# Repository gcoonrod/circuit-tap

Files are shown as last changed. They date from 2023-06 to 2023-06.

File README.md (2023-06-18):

<!--
 Copyright 2023 Greg Coonrod
 
 Licensed under the Apache License, Version 2.0 (the "License");
 you may not use this file except in compliance with the License.
 You may obtain a copy of the License at
 
     http://www.apache.org/licenses/LICENSE-2.0
 
 Unless required by applicable law or agreed to in writing, software
 distributed under the License is distributed on an "AS IS" BASIS,
 WITHOUT WARRANTIES OR CONDITIONS OF ANY KIND, either express or implied.
 See the License for the specific language governing permissions and
 limitations under the License.
-->

# Circuit Tap

A low-speed digital logic analyzer designed around 74HC165 shift registers and the ATMega4809 MCU.

## Design

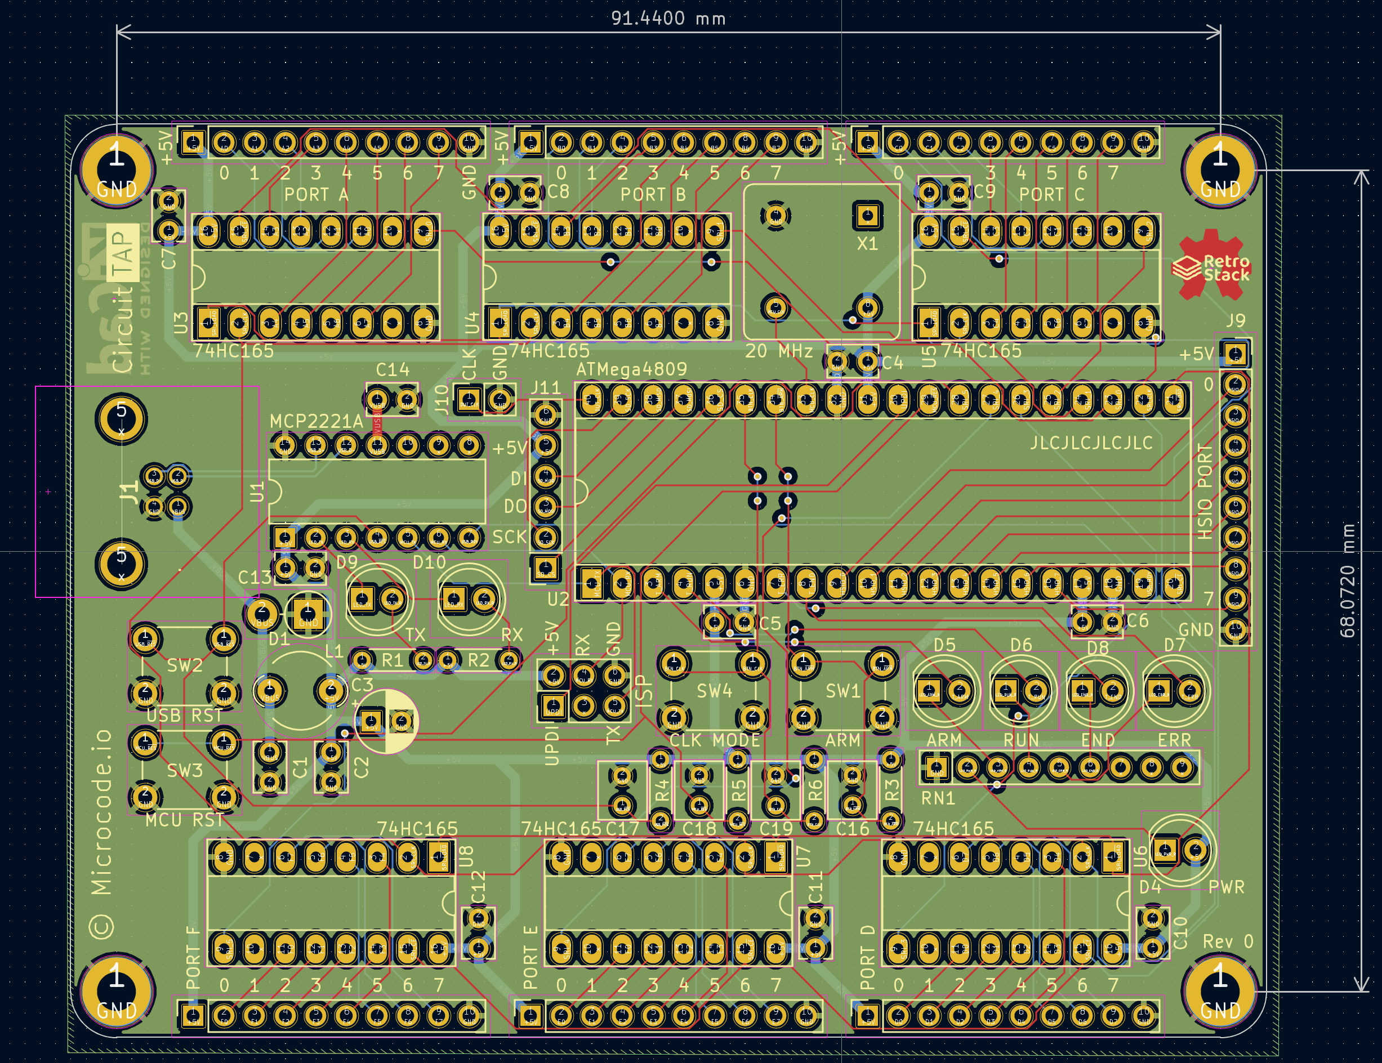
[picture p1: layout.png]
layout


The Circuit Tap is designed to serve as a digital logic analyzer for primarily low speed circuits (<= 1Mhz). It is intended to aid in debugging the [RetroStack](https://github.com/gcoonrod/retro-stack), a 6502 based hobbyist computer. As I do not (at the time of designing this tool) own an oscilliscope or logic analyzer, I needed a way to monitor the address bus, data bus, and numerous control signals of the RetroStack while the clock was freely running. For very simple programs it was sufficient to use a manually stepped clock to debug, but the addition of IO peripherals and more complex programs have made it prohibitively time consuming to continue manual clock control.

### Data Capture

The Circuit Tap has 6 low speed 8-bit input ports and one full speed 8-bit port. The low speed ports are implemented with 74HC165 parallel load shift registers which allows for the simultaneous capture of up to 48 signals on a single clock transition. However, those bits must be shifted out before (~10 mcu clock cycles) before another sample can be taken. This is the primary limiting factor for the sampling speed of the low speed inputs. The full speed port is directly mapped to Port D of the 4809 and can be read from or written to as fast as the mcu is capable.

### Goals

- Reliably capture signals at ~1Mhz
- Read test plans from an SD card or UART
- Write test results to SD or UART
- Integrate with desktop GUI (TBD)
- Drive external clock and control lines
- Trigger off external clock and control lines

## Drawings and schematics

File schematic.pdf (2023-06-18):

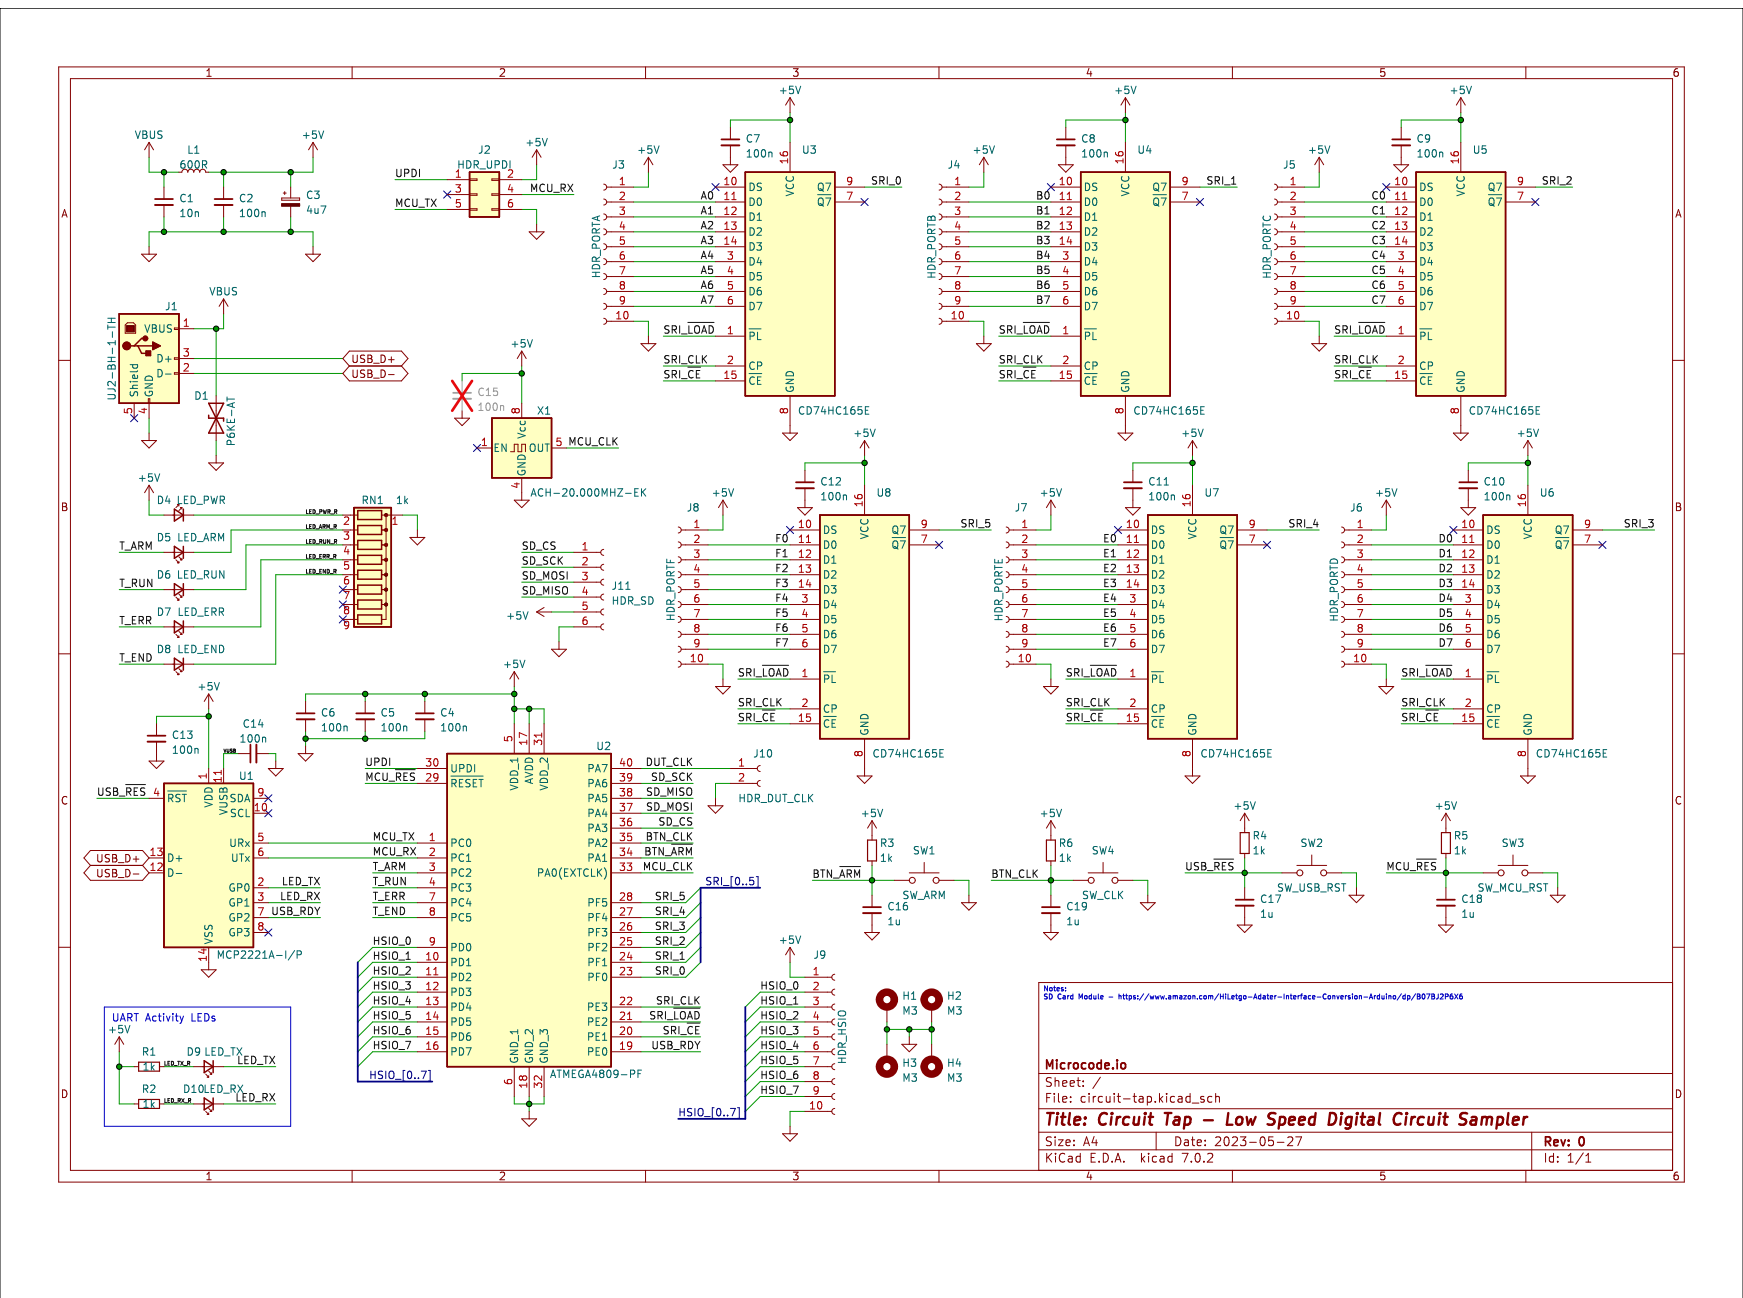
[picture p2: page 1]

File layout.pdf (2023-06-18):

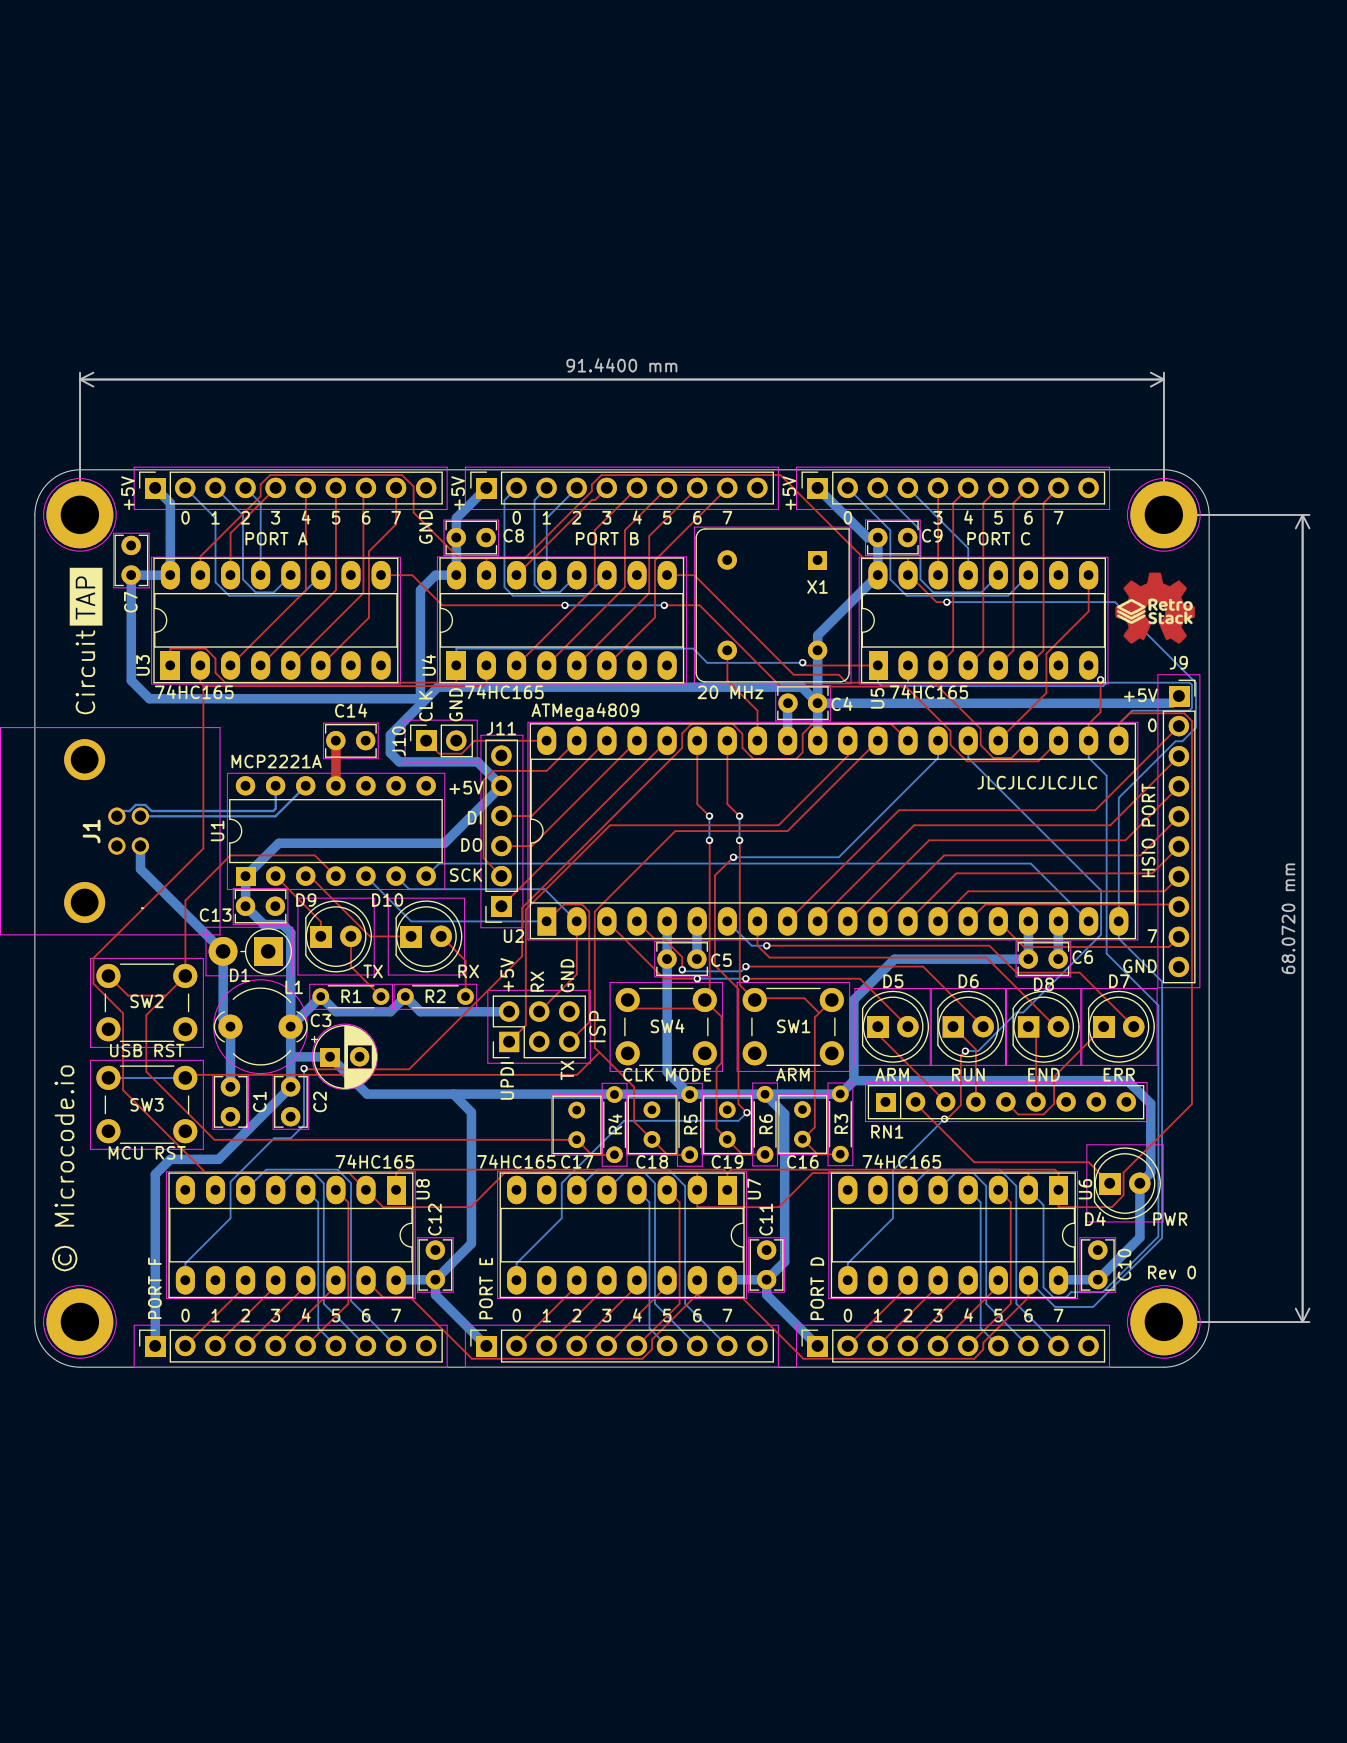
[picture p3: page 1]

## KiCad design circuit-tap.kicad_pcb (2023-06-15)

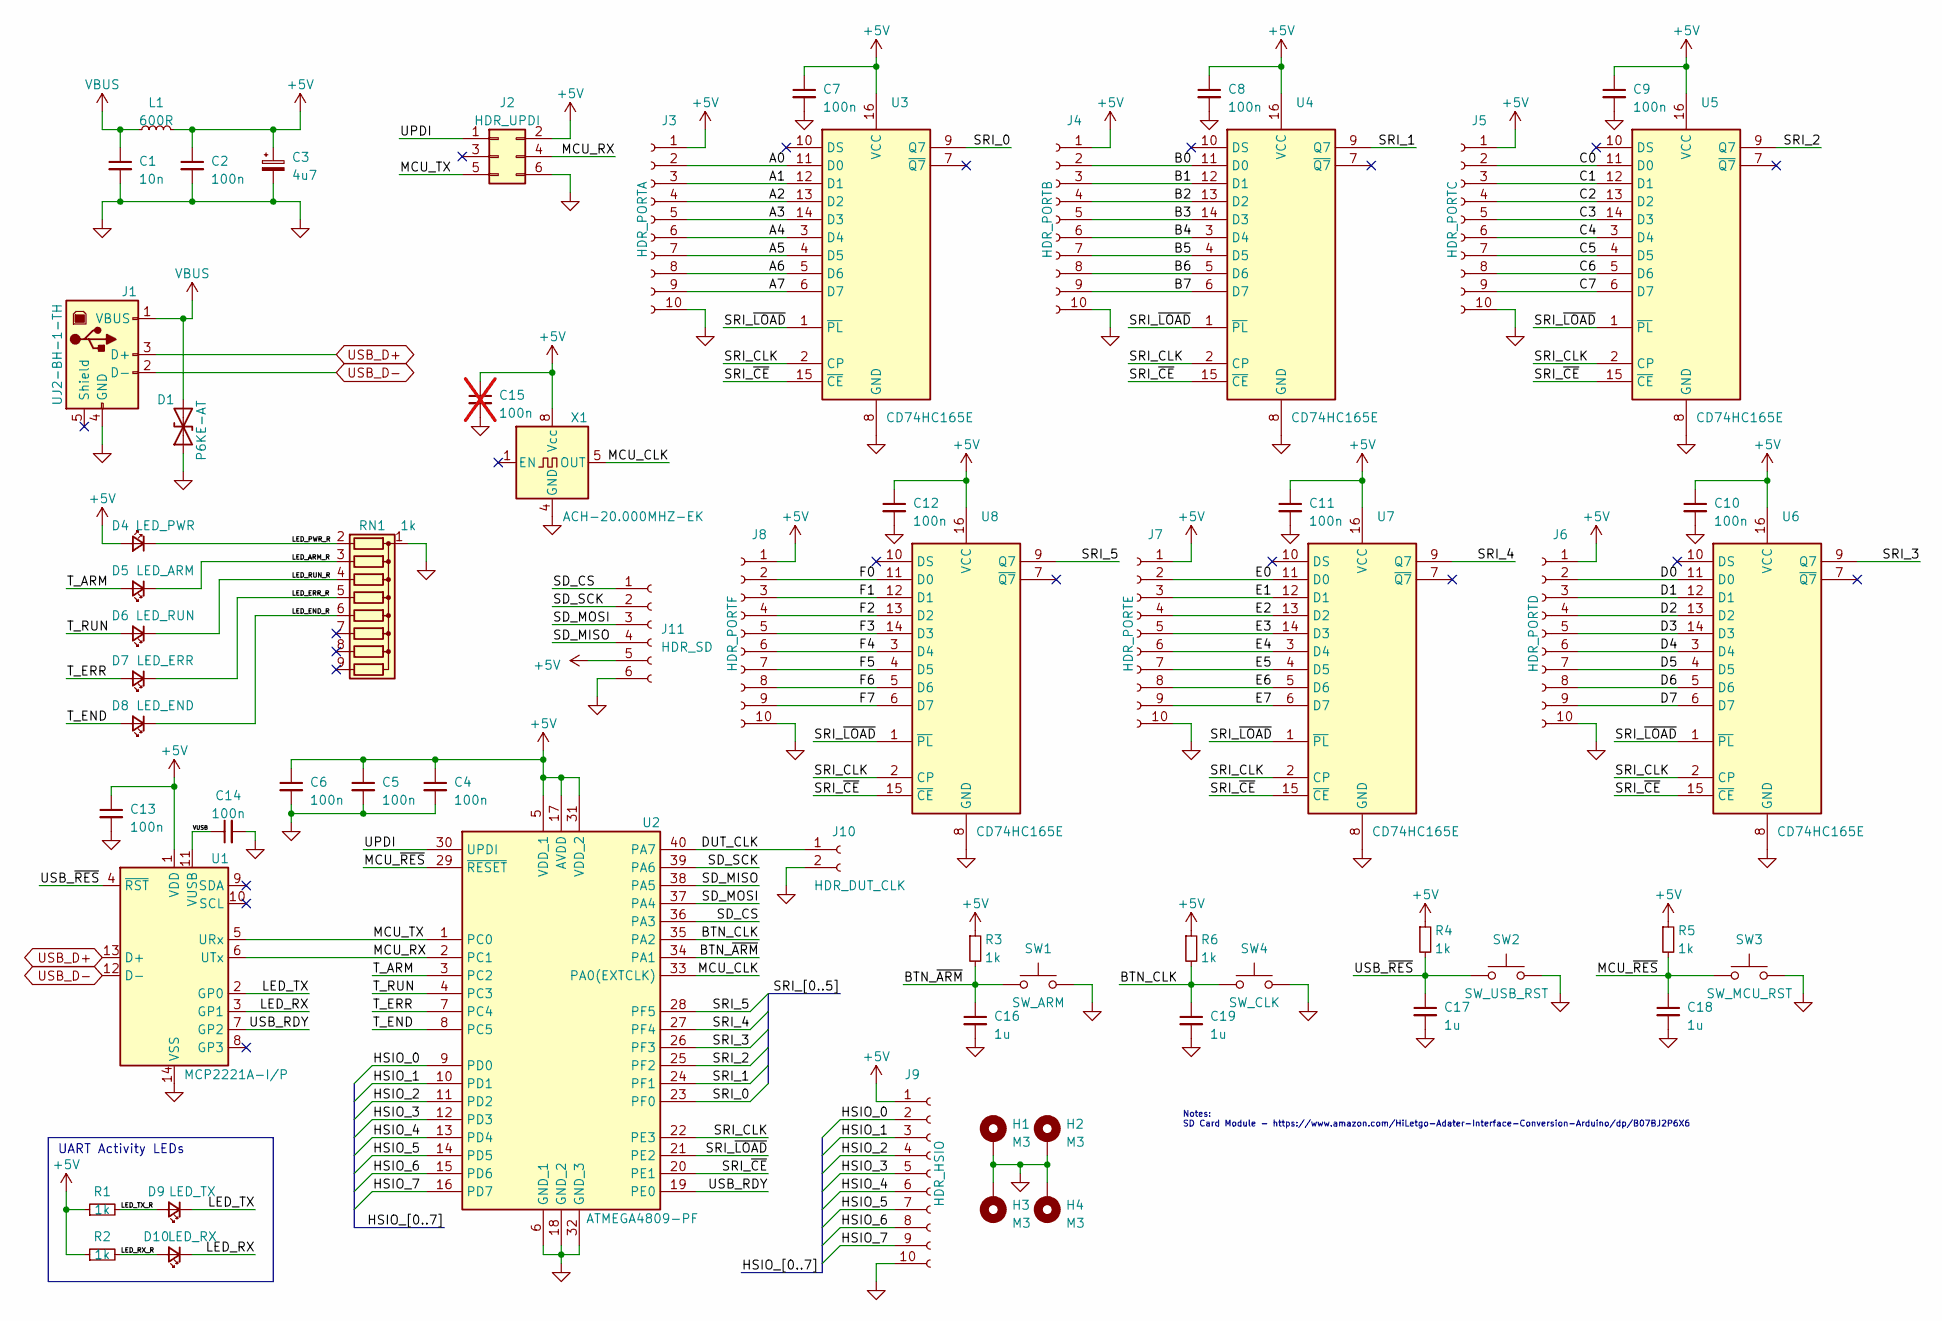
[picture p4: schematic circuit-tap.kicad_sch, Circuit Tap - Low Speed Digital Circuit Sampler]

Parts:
C1: 10n; C_Rect_L4.0mm_W2.5mm_P2.50mm; Manufacturer Part K103K10X7RF53L2
C2, C4, C5, C6, C7, C8, C9, C10, C11, C12, C13, C14: 100n; C_Rect_L4.0mm_W2.5mm_P2.50mm; Manufacturer Part K104K15X7RF5TL2
C3: 4u7; CP_Radial_D5.0mm_P2.50mm; Manufacturer Part ECE-A1VKS4R7I
C15: 100n; C_Rect_L4.0mm_W2.5mm_P2.50mm; Manufacturer Part K104K15X7RF5TL2; not fitted
C16, C17, C18, C19: 1u; C_Rect_L4.6mm_W3.8mm_P2.50mm_MKS02_FKP02; Manufacturer Part FG18X7R1E105KRT00
D1: P6KE-AT; D_DO-15_P3.81mm_Vertical_AnodeUp; Manufacturer Part P6KE6.8CA-AT/B
D4: LED_PWR; LED_D5.0mm; Manufacturer Part WP7113ID
D5: LED_ARM; LED_D5.0mm; Manufacturer Part WP7113YT
D6: LED_RUN; LED_D5.0mm; Manufacturer Part WP7113GD
D7: LED_ERR; LED_D5.0mm; Manufacturer Part WP7113ID
D8: LED_END; LED_D5.0mm; Manufacturer Part WP7113GD
D9: LED_TX; LED_D5.0mm; Manufacturer Part WP7113YT
D10: LED_RX; LED_D5.0mm; Manufacturer Part WP7113YT
H1, H2, H3, H4: M3; MountingHole_3.2mm_M3_DIN965_Pad
J1: UJ2-BH-1-TH; UJ2BH1TH; Manufacturer Part UJ2-BH-1-TH
J2: HDR_UPDI; PinHeader_2x03_P2.54mm_Vertical; Manufacturer Part 10129381-906002BLF
J3: HDR_PORTA; PinSocket_1x10_P2.54mm_Vertical; Manufacturer Part 61301011821
J4: HDR_PORTB; PinSocket_1x10_P2.54mm_Vertical; Manufacturer Part 61301011821
J5: HDR_PORTC; PinSocket_1x10_P2.54mm_Vertical; Manufacturer Part 61301011821
J6: HDR_PORTD; PinSocket_1x10_P2.54mm_Vertical; Manufacturer Part 61301011821
J7: HDR_PORTE; PinSocket_1x10_P2.54mm_Vertical; Manufacturer Part 61301011821
J8: HDR_PORTF; PinSocket_1x10_P2.54mm_Vertical; Manufacturer Part 61301011821
J9: HDR_HSIO; PinSocket_1x10_P2.54mm_Vertical; Manufacturer Part 61301011821
J10: HDR_DUT_CLK; PinSocket_1x02_P2.54mm_Vertical; Manufacturer Part 801-87-002-10-001101
J11: HDR_SD; PinSocket_1x06_P2.54mm_Vertical; Manufacturer Part 61300611821
L1: 600R; LairdTech_28C0236-0JW-10; Manufacturer Part 28C0236-0JW-10
R1, R2, R3, R4, R5, R6: 1k; R_Axial_DIN0204_L3.6mm_D1.6mm_P5.08mm_Horizontal; Manufacturer Part MBA02040C1001FCT00
RN1: 1k; R_Array_SIP9; Manufacturer Part 4609X-101-102LF
SW1: SW_ARM; SW_PUSH_6mm; Manufacturer Part TS02-66-70-BK-260-LCR-D
SW2: SW_USB_RST; SW_PUSH_6mm; Manufacturer Part FSM4JAH
SW3: SW_MCU_RST; SW_PUSH_6mm; Manufacturer Part FSM4JAH
SW4: SW_CLK; SW_PUSH_6mm; Manufacturer Part TS02-66-70-BK-260-LCR-D
U1: MCP2221A-I/P; DIP-14_W7.62mm; Manufacturer Part MCP2221A-I/P
U2: ATMEGA4809-PF; DIP-40_W15.24mm_Socket_LongPads; Manufacturer Part ATMEGA4809-PF
U3, U4, U5, U6, U7, U8: CD74HC165E; DIP-16_W7.62mm_Socket_LongPads; Manufacturer Part CD74HC165E
X1: ACH-20.000MHZ-EK; Oscillator_DIP-8; Manufacturer Part ACH-20.000MHZ-EK

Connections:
+5V: C2.1, C3.1, C4.1, C5.1, C6.1, C7.1, C8.1, C9.1, C10.1, C11.1, C12.1, C13.1, C15.1, D4.2 (A), J2.2, J3.1, J4.1, J5.1, J6.1, J7.1, J8.1, J9.1, J11.5, L1.2, R1.1, R2.1, R3.1, R4.1, R5.1, R6.1, U1.1 (VDD), U2.5 (VDD_1), U2.17 (AVDD), U2.31 (VDD_2), U3.16 (VCC), U4.16 (VCC), U5.16 (VCC), U6.16 (VCC), U7.16 (VCC), U8.16 (VCC), X1.8 (Vcc)
/A0: J3.2, U3.11 (D0)
/A1: J3.3, U3.12 (D1)
/A2: J3.4, U3.13 (D2)
/A3: J3.5, U3.14 (D3)
/A4: J3.6, U3.3 (D4)
/A5: J3.7, U3.4 (D5)
/A6: J3.8, U3.5 (D6)
/A7: J3.9, U3.6 (D7)
/B0: J4.2, U4.11 (D0)
/B1: J4.3, U4.12 (D1)
/B2: J4.4, U4.13 (D2)
/B3: J4.5, U4.14 (D3)
/B4: J4.6, U4.3 (D4)
/B5: J4.7, U4.4 (D5)
/B6: J4.8, U4.5 (D6)
/B7: J4.9, U4.6 (D7)
/BTN_CLK: C19.1, R6.2, SW4.1, U2.35 (PA2)
/BTN_~ARM: C16.1, R3.2, SW1.1, U2.34 (PA1)
/C0: J5.2, U5.11 (D0)
/C1: J5.3, U5.12 (D1)
/C2: J5.4, U5.13 (D2)
/C3: J5.5, U5.14 (D3)
/C4: J5.6, U5.3 (D4)
/C5: J5.7, U5.4 (D5)
/C6: J5.8, U5.5 (D6)
/C7: J5.9, U5.6 (D7)
/D0: J6.2, U6.11 (D0)
/D1: J6.3, U6.12 (D1)
/D2: J6.4, U6.13 (D2)
/D3: J6.5, U6.14 (D3)
/D4: J6.6, U6.3 (D4)
/D5: J6.7, U6.4 (D5)
/D6: J6.8, U6.5 (D6)
/D7: J6.9, U6.6 (D7)
/DUT_CLK: J10.1, U2.40 (PA7)
/E0: J7.2, U7.11 (D0)
/E1: J7.3, U7.12 (D1)
/E2: J7.4, U7.13 (D2)
/E3: J7.5, U7.14 (D3)
/E4: J7.6, U7.3 (D4)
/E5: J7.7, U7.4 (D5)
/E6: J7.8, U7.5 (D6)
/E7: J7.9, U7.6 (D7)
/F0: J8.2, U8.11 (D0)
/F1: J8.3, U8.12 (D1)
/F2: J8.4, U8.13 (D2)
/F3: J8.5, U8.14 (D3)
/F4: J8.6, U8.3 (D4)
/F5: J8.7, U8.4 (D5)
/F6: J8.8, U8.5 (D6)
/F7: J8.9, U8.6 (D7)
/HSIO_0: J9.2, U2.9 (PD0)
/HSIO_1: J9.3, U2.10 (PD1)
/HSIO_2: J9.4, U2.11 (PD2)
/HSIO_3: J9.5, U2.12 (PD3)
/HSIO_4: J9.6, U2.13 (PD4)
/HSIO_5: J9.7, U2.14 (PD5)
/HSIO_6: J9.8, U2.15 (PD6)
/HSIO_7: J9.9, U2.16 (PD7)
/LED_ARM_R: D5.1 (K), RN1.3 (R2)
/LED_END_R: D8.1 (K), RN1.6 (R5)
/LED_ERR_R: D7.1 (K), RN1.5 (R4)
/LED_PWR_R: D4.1 (K), RN1.2 (R1)
/LED_RUN_R: D6.1 (K), RN1.4 (R3)
/LED_RX: D10.1 (K), U1.3 (GP1)
/LED_RX_R: D10.2 (A), R2.2
/LED_TX: D9.1 (K), U1.2 (GP0)
/LED_TX_R: D9.2 (A), R1.2
/MCU_CLK: U2.33 (PA0(EXTCLK)), X1.5 (OUT)
/MCU_RX: J2.4, U1.6 (UTx), U2.2 (PC1)
/MCU_TX: J2.5, U1.5 (URx), U2.1 (PC0)
/MCU_~RES: C18.1, R5.2, SW3.1, U2.29 (~RESET)
/SD_CS: J11.1, U2.36 (PA3)
/SD_MISO: J11.4, U2.38 (PA5)
/SD_MOSI: J11.3, U2.37 (PA4)
/SD_SCK: J11.2, U2.39 (PA6)
/SRI_0: U2.23 (PF0), U3.9 (Q7)
/SRI_1: U2.24 (PF1), U4.9 (Q7)
/SRI_2: U2.25 (PF2), U5.9 (Q7)
/SRI_3: U2.26 (PF3), U6.9 (Q7)
/SRI_4: U2.27 (PF4), U7.9 (Q7)
/SRI_5: U2.28 (PF5), U8.9 (Q7)
/SRI_CLK: U2.22 (PE3), U3.2 (CP), U4.2 (CP), U5.2 (CP), U6.2 (CP), U7.2 (CP), U8.2 (CP)
/SRI_~CE: U2.20 (PE1), U3.15 (~CE), U4.15 (~CE), U5.15 (~CE), U6.15 (~CE), U7.15 (~CE), U8.15 (~CE)
/SRI_~LOAD: U2.21 (PE2), U3.1 (~PL), U4.1 (~PL), U5.1 (~PL), U6.1 (~PL), U7.1 (~PL), U8.1 (~PL)
/T_ARM: D5.2 (A), U2.3 (PC2)
/T_END: D8.2 (A), U2.8 (PC5)
/T_ERR: D7.2 (A), U2.7 (PC4)
/T_RUN: D6.2 (A), U2.4 (PC3)
/UPDI: J2.1, U2.30 (UPDI)
/USB_RDY: U1.7 (GP2), U2.19 (PE0)
/USB_~RES: C17.1, R4.2, SW2.1, U1.4 (~RST)
/VUSB: C14.1, U1.11 (VUSB)
GND: C1.2, C2.2, C3.2, C4.2, C5.2, C6.2, C7.2, C8.2, C9.2, C10.2, C11.2, C12.2, C13.2, C14.2, C15.2, C16.2, C17.2, C18.2, C19.2, D1.1 (A1), H1.1, H2.1, H3.1, H4.1, J1.4 (GND), J2.6, J3.10, J4.10, J5.10, J6.10, J7.10, J8.10, J9.10, J10.2, J11.6, RN1.1 (common), SW1.2, SW2.2, SW3.2, SW4.2, U1.14 (VSS), U2.6 (GND_1), U2.18 (GND_2), U2.32 (GND_3), U3.8 (GND), U4.8 (GND), U5.8 (GND), U6.8 (GND), U7.8 (GND), U8.8 (GND), X1.4 (GND)
USB_D+: J1.3 (D+), U1.13 (D+)
USB_D-: J1.2 (D-), U1.12 (D-)
VBUS: C1.1, D1.2 (A2), J1.1 (VBUS), L1.1

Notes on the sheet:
Notes: SD Card Module - https://www.amazon.com/HiLetgo-Adater-Interface-Conversion-Arduino/dp/B07BJ2P6X6
UART Activity LEDs

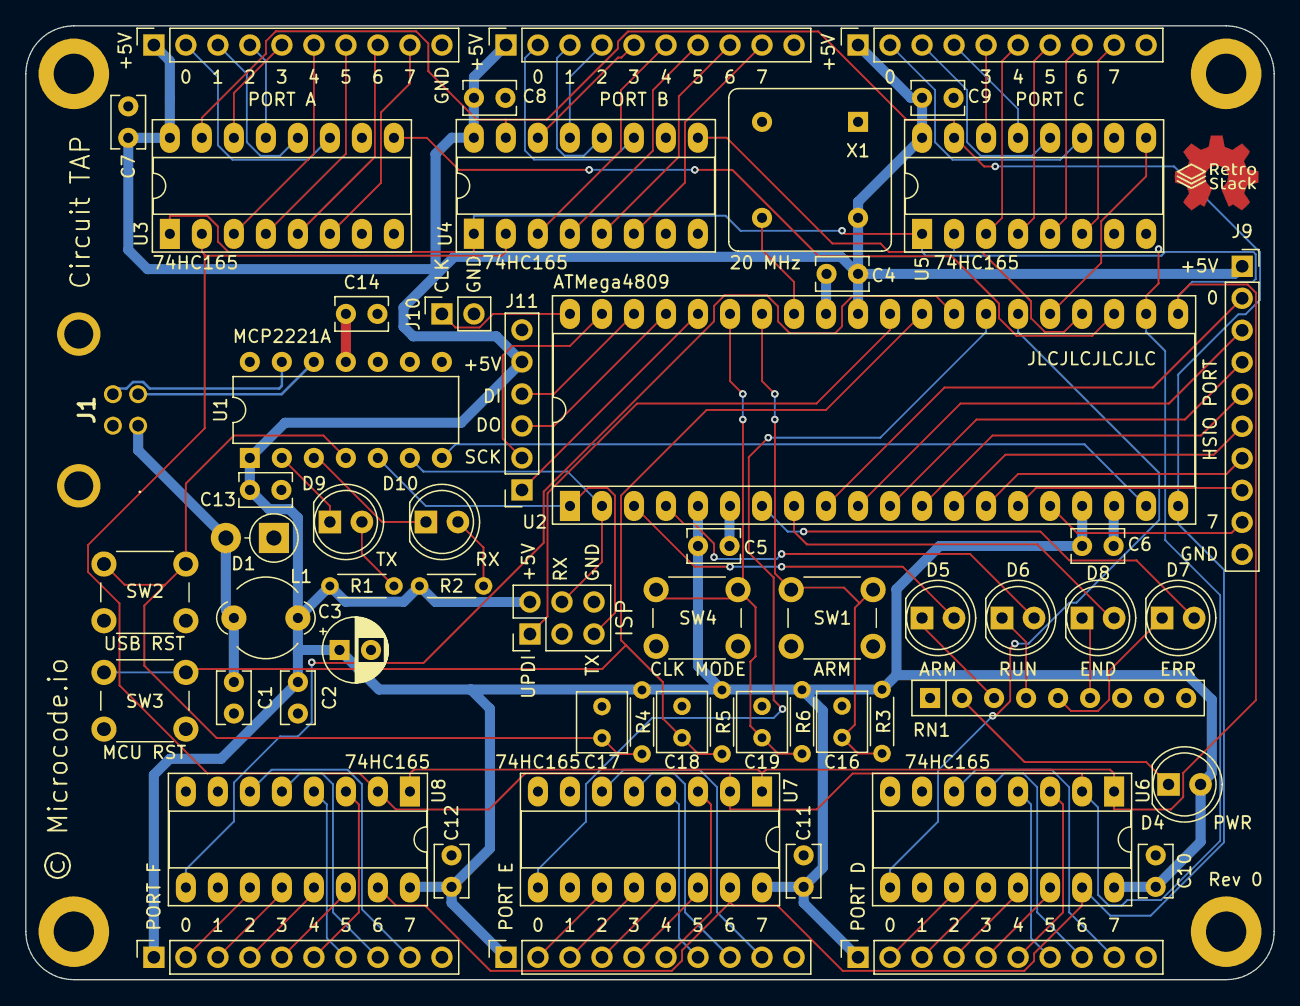
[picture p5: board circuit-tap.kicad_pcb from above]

Board: 4 copper layers, 99.1 x 75.7 mm, 62 parts (0 on the bottom side), 98 nets.

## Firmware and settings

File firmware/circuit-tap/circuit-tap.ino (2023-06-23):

// Copyright 2023 Greg Coonrod
//
// Licensed under the Apache License, Version 2.0 (the "License");
// you may not use this file except in compliance with the License.
// You may obtain a copy of the License at
//
//     http://www.apache.org/licenses/LICENSE-2.0
//
// Unless required by applicable law or agreed to in writing, software
// distributed under the License is distributed on an "AS IS" BASIS,
// WITHOUT WARRANTIES OR CONDITIONS OF ANY KIND, either express or implied.
// See the License for the specific language governing permissions and
// limitations under the License.

#define F_CPU 20000000UL
#define __DEBUG__

// Library and System Includes
#include <Arduino.h>
#include <avr/io.h>
#include <SPI.h>
#include <SD.h>

// Local Includes
#include "src/CircuitTap.h"

// Circuit Tap

// Define pins on the ATMega4809 40-pin DIP package
// UART 1 default pins
#define MCU_TX PIN_PC0
#define MCU_RX PIN_PC1

// State LEDs
#define T_ARM PIN_PC2
#define T_RUN PIN_PC3
#define T_ERR PIN_PC4
#define T_END PIN_PC5

// High Speed IO (HSIO) uses Port D [0..7]
// Use the native AVR port registers for speed
#define HSIO_PORT PORTD
#define HSIO_DDR PORTD.DIR
#define HSIO_PIN PORTD.PIN
#define HSIO_MASK 0b00000000

// SPI Pins and Selects
// Primarily intended for SD card use
#define SPI_MOSI PIN_SPI_MOSI
#define SPI_MISO PIN_SPI_MISO
#define SPI_SCK PIN_SPI_SCK
#define SPI_CS PIN_PA3

// Buttons
// All active low
#define BTN_MODE PIN_PA2
#define BTN_ARM PIN_PA1

// Device Under Test (DUT) Clock IO
#define DUT_CLK PIN_PA7

// MCP2221A USB Ready Signal
#define USB_RDY PIN_PE0

// Global Variables/State


// Global FSM
static StateManager manager;
SRPortManager srPort;

// LEDs Setup
void setup_leds()
{
    pinMode(T_ARM, OUTPUT);
    pinMode(T_RUN, OUTPUT);
    pinMode(T_ERR, OUTPUT);
    pinMode(T_END, OUTPUT);
}

// Buttons Setup
void setup_btns()
{
    pinMode(BTN_ARM, INPUT);
    pinMode(BTN_MODE, INPUT);
}

// HSIO Port Setup
void setup_hsio_port(uint8_t bitmask)
{
    HSIO_DDR = bitmask;
}

// SPI Setup
void setup_spi()
{
    pinMode(SPI_MOSI, OUTPUT);
    pinMode(SPI_MISO, INPUT);
    pinMode(SPI_SCK, OUTPUT);
    pinMode(SPI_CS, OUTPUT);

    // Disable CS by default
    digitalWrite(SPI_CS, HIGH);
}

// USB Ready Setup
void setup_usb_rdy()
{
    pinMode(USB_RDY, INPUT);
}

// DUT Clock Setup
void setup_dut_clk()
{
    pinMode(DUT_CLK, INPUT);
}

// Setup SD Card
void setup_sd()
{
    // Setup SPI
    setup_spi();

    // Setup SD Card
    if (!SD.begin(SPI_CS))
    {
        Serial1.println("SD Card failed to initialize");
        manager.setErrorState(true);
    }
    Serial1.println("SD Card initialized");
}

// Button ISRs
void btn_arm_isr()
{
    Serial1.println("ARM Button Pressed");
    if (manager.getArmState() == FSM::ArmState::Disarmed)
    {
        // If Disarmed and Running, End
        if (manager.getRunState() == FSM::RunState::Running)
        {
            manager.setRunState(FSM::RunState::Ended);
        }
        else if (manager.getRunState() == FSM::RunState::Ended)
        {
            manager.setRunState(FSM::RunState::Stopped);
        }
        else
        {
            manager.setArmState(FSM::ArmState::Armed);
        }
    }
    else
    {
        manager.setArmState(FSM::ArmState::Disarmed);
    }
}

void btn_mode_isr()
{
    Serial1.println("MODE Button Pressed");
    manager.cycleClkModeState();
}

// DUT Clock ISR
void dut_clk_isr()
{

    // If armed, start running and disarm
    if (manager.getArmState() == FSM::ArmState::Armed)
    {
        Serial1.println(F("Run started by DUT Clock Interrupt"));
        manager.setRunState(FSM::RunState::Running);
        manager.setArmState(FSM::ArmState::Disarmed);
    }

    // If running, trigger SR latch and shift in data
    if (manager.getRunState() == FSM::RunState::Running)
    {
        Serial1.println(F("Placeholder for SR Latch Trigger"));
        // TODO Trigger SR Latch and Shift in Data
        // TODO if ISR is triggered before Shift in is complete set Error state and end run
    }

    // If ended or stopped do nothing
    if (manager.getRunState() == FSM::RunState::Ended || manager.getRunState() == FSM::RunState::Stopped)
    {
#ifdef __DEBUG__
        Serial1.println(F("DUT Clock ISR while Stopped or Ended"));
#endif
        return;
    }
}

// LED Update
void updateLEDs(StateManager *manager)
{
    // Update ARM LED
    digitalWrite(T_ARM, manager->getArmState() == FSM::ArmState::Armed ? 1 : 0);

    // Update RUN and END LEDs
    switch (manager->getRunState())
    {
    case FSM::RunState::Running:
        digitalWrite(T_RUN, 1);
        digitalWrite(T_END, 0);
        break;
    case FSM::RunState::Stopped:
        digitalWrite(T_RUN, 0);
        digitalWrite(T_END, 0);
        break;
    case FSM::RunState::Ended:
        digitalWrite(T_RUN, 0);
        digitalWrite(T_END, 1);
        break;
    }

    // Update ERR LED
    digitalWrite(T_ERR, manager->getErrorState() ? 1 : 0);
}

// DUT Clock Update
void updateDUTClk(StateManager *manager)
{
    // Do nothing if RunState is Running
    if (manager->getRunState() == FSM::RunState::Running)
    {
        // A test is running, do not make any changes to
        return;
    }

    // Update DUT Clock
    switch (manager->getClkModeState())
    {
        // Output Mode, Disable DUT Clock Interrupt
    case FSM::ClkModeState::Output:
        detachInterrupt(DUT_CLK);
        pinMode(DUT_CLK, OUTPUT);
        break;
        // Input Mode, Enable DUT Clock Interrupt if Armed
    case FSM::ClkModeState::Input:
        if (manager->getArmState() == FSM::ArmState::Armed)
        {
            attachInterrupt(DUT_CLK, dut_clk_isr, FALLING);
        }
        else
        {
            detachInterrupt(DUT_CLK);
        }
        pinMode(DUT_CLK, INPUT_PULLUP);
        break;
        // HighZ Mode, Disable DUT Clock Interrupt
    case FSM::ClkModeState::HighZ:
        detachInterrupt(DUT_CLK);
        pinMode(DUT_CLK, INPUT);
        break;
    }
}

// Arduino Functions
void setup()
{

    // Setup State Manager
    manager = StateManager();

    // Setup SR Port Manager
    srPort = SRPortManager();
    srPort.begin();

    // Setup LEDs
    setup_leds();

    // Setup Buttons
    setup_btns();

    // Setup HSIO Port
    setup_hsio_port(HSIO_MASK);

    // Setup SPI
    setup_spi();

    // Setup USB Ready
    setup_usb_rdy();

    // Setup DUT Clock
    setup_dut_clk();

    // Attach ISRs
    attachInterrupt(BTN_ARM, btn_arm_isr, FALLING);
    attachInterrupt(BTN_MODE, btn_mode_isr, FALLING);

    Serial1.begin(115200);
    Serial1.println("Circuit Tap - Started");
}

void loop()
{
    // Update LEDs based on current state
    updateLEDs(&manager);

    // Update DUT clock based on current state
    updateDUTClk(&manager);

#ifdef __DEBUG__
    // Print Current State from State Manager to Serial
    if (manager.isDirty())
    {
        Serial1.println(manager);
    }
#endif

    // Update State Manager
    manager.update();
}

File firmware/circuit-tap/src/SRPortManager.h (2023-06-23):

// Copyright 2023 Greg Coonrod
//
// Licensed under the Apache License, Version 2.0 (the "License");
// you may not use this file except in compliance with the License.
// You may obtain a copy of the License at
//
//     http://www.apache.org/licenses/LICENSE-2.0
//
// Unless required by applicable law or agreed to in writing, software
// distributed under the License is distributed on an "AS IS" BASIS,
// WITHOUT WARRANTIES OR CONDITIONS OF ANY KIND, either express or implied.
// See the License for the specific language governing permissions and
// limitations under the License.

#ifndef SRPORTMANAGER_H
#define SRPORTMANAGER_H

#include <Arduino.h>
#include <avr/io.h>

#define SRI_PORT_COUNT 6

// Shift Register Inputs (SRI) Control Pins
#define SRI_CTRL_PORT PORTE
#define SRI_CEB_PIN PIN_PE1   // Active Low
#define SRI_LOADB_PIN PIN_PE2 // Active Low
#define SRI_CLK_PIN PIN_PE3

#define SRI_CEB_bm PIN1_bm
#define SRI_LOADB_bm PIN2_bm
#define SRI_CLK_bm PIN3_bm

// Shift Register Inputs (SRI) Data Pins Port F [0..5]
// Uses the native AVR port registers for speed
// PF6 reserved for RESETB
// All pins are input only
#define SRI_DATA_PORT PORTF
#define SRI_DATA_DDR PORTF.DIR
#define SRI_DATA_PIN PORTF.PIN
#define SRI_DATA_MASK 0b0000000

#define SRI_PORTA_bm PIN0_bm
#define SRI_PORTB_bm PIN1_bm
#define SRI_PORTC_bm PIN2_bm
#define SRI_PORTD_bm PIN3_bm
#define SRI_PORTE_bm PIN4_bm
#define SRI_PORTF_bm PIN5_bm

/**
 * Shift Register Port Manager Class
 * The SRPortManager is intended to manage the interactions with the shift registers
 * that make up the low-speed input ports A through F of the Circuit Tap. The six shift
 * registers (74HC165) are joined in parallel to form a 48-bit shift register. The control
 * lines for the shift registers are connected to Port E (PE1-PE3) of the ATMega4809. The
 * serial data out (QH) of each shift register is connected to Port F (PF0-PF5) of the
 * ATMega4809.
 */
class SRPortManager
{
public:
    // Constructor
    SRPortManager();

    void begin();

    void shiftInAllPorts();
    
    uint8_t shiftInPort(uint8_t port);

    static uint8_t getByte(uint8_t index);

private:
    static uint8_t _shiftData[SRI_PORT_COUNT];
};

#endif

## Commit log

2023-06-15 Board rev 0
    [circuit-tap.kicad_pcb, circuit-tap.kicad_sch]
2023-06-18 Docs updates and WIP firmware.
    [circuit-tap.kicad_sch]
2023-06-23 Wip before switching to platformio

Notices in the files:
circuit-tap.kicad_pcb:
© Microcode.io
